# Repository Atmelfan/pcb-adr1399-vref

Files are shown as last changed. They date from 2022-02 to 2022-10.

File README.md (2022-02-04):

# pcb-adr1399-vref

**NOTICE** - The main branch is probably not production ready. Check out [Releases](https://github.com/Atmelfan/pcb-adr1399-vref/releases) for finished revisions.

A simple 10 V voltage reference based on [ADR1399](https://www.analog.com/en/products/adr1399.html) from Analog Devices.

# Schematic
Schematic
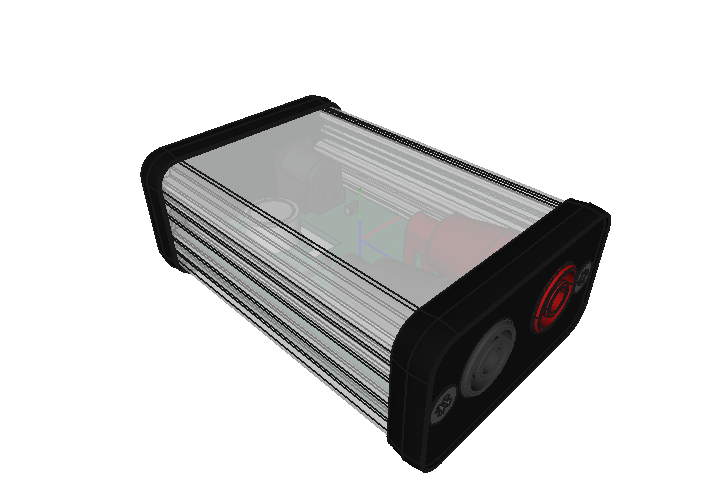
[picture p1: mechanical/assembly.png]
Assembly view


Check out [Releases](https://github.com/Atmelfan/pcb-adr1399-vref/releases) for revision schematics and materials.

# Tools used
* Schematic & Layout - [KiCad 6](https://www.kicad.org/)
* Assembly - [FreeCad 0.19](https://www.freecadweb.org/)

# License
This work is licensed under [CERN Open Hardware Licence Version 2 - Strongly Reciprocal](https://www.ohwr.org/project/cernohl/wikis/Documents/CERN-OHL-version-2).

See [LICENSE.txt](LICENSE.txt) for full text.

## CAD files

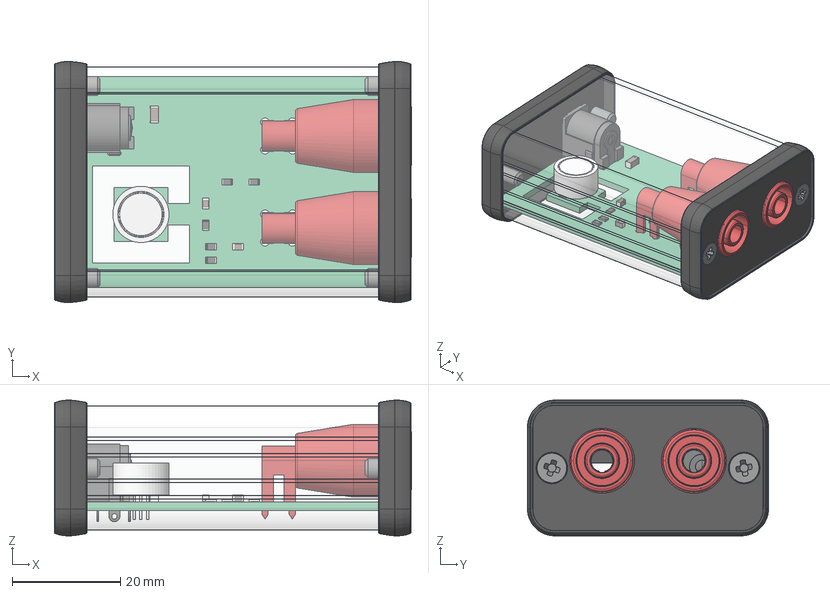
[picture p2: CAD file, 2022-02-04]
mechanical/assembly.step
66.1 x 44.6 x 25.1 mm
Extrusion Tube w. Inlay 60mm x 2
1455 Black screw x 2
1455 Black screw001 x 2
1455 Black screw002 x 2
1455 Black screw003 x 2
LCS x 2
Front Bezel x 2
Back Bezel x 2
Pcb_1364 x 2
J1_54-00130_0b9d4587839c x 2
R2_R_0805_2012Metric_4d09f17c0e32 x 10
C4_C_0805_2012Metric_924e94be286f x 6
J3_CT3151SP_0_b83ad89091ef x 4
U1_Analog_TO-46-4_ThermalShield_8fb0bece400e x 2
C1_C_1206_3216Metric_b3bb6e5f0510 x 2
LCS_Origin x 2

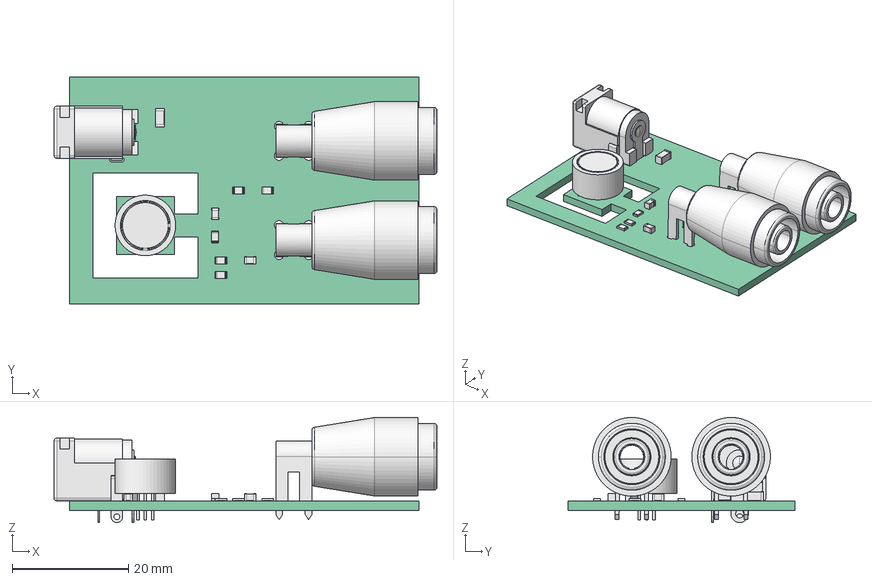
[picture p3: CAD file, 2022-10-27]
mechanical/board.FCStd
65.8 x 39.0 x 18.0 mm
Pcb_1364
J1_54-00130_0b9d4587839c
R2_R_0805_2012Metric_4d09f17c0e32 x 5
C4_C_0805_2012Metric_924e94be286f x 3
J3_CT3151SP_0_b83ad89091ef x 2
U1_Analog_TO-46-4_ThermalShield_8fb0bece400e
C1_C_1206_3216Metric_b3bb6e5f0510

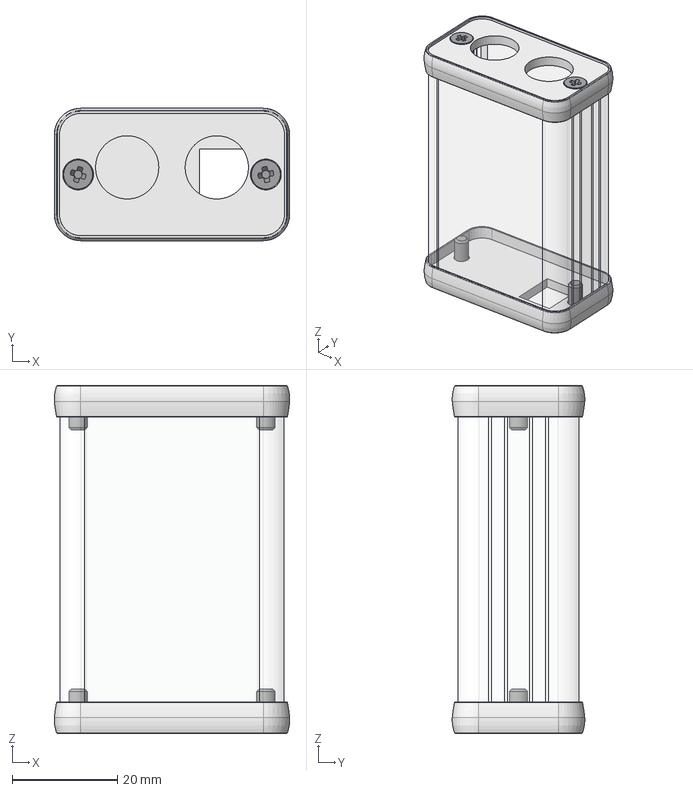
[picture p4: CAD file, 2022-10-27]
mechanical/box.FCStd
44.6 x 25.1 x 66.0 mm
Extrusion Tube w. Inlay 60mm
1455 Black screw
1455 Black screw001
1455 Black screw002
1455 Black screw003
Front Bezel
Back Bezel

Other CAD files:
mechanical/pcb.FCStd
mechanical/1455D602.stp
mechanical/assembly.FCStd
mechanical/assembly.stl

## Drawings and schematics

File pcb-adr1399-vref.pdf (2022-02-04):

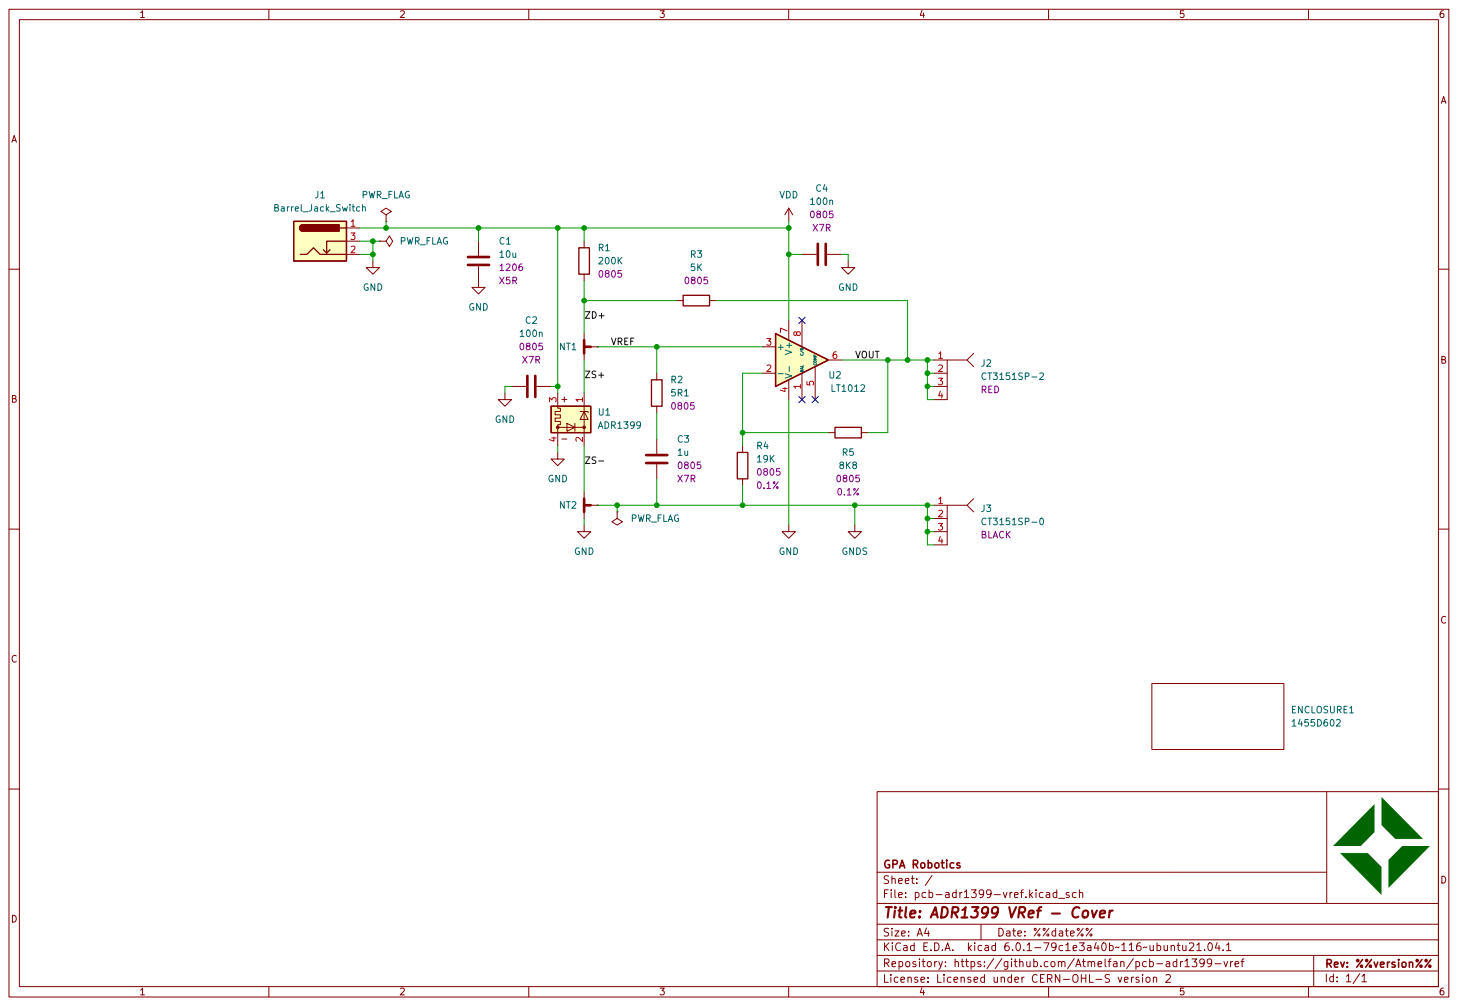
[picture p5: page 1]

File: pcb-adr1399-vref.kicad_sch Sheet: / GPA Robotics Repository: https://github.com/Atmelfan/pcb-adr1399-vref License: Licensed under CERN-OHL-S version 2 GND

D Date: %%date%%

Id: 1/1 Title: ADR1399 VRef - Cover

Size: A4

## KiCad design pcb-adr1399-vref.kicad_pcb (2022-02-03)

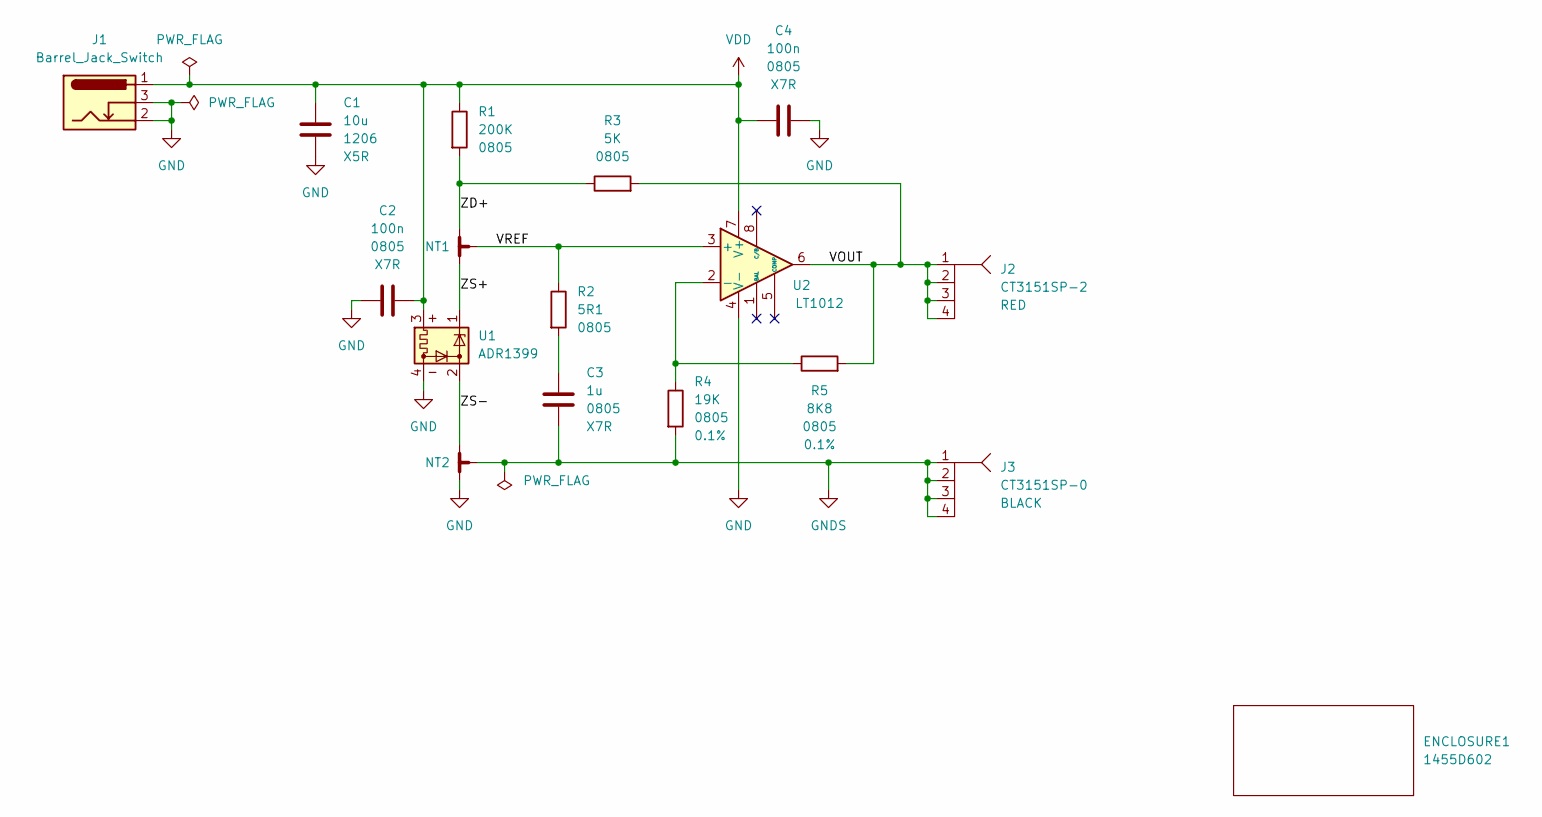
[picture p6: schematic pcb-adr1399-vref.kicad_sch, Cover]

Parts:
C1: 10u; C_1206_3216Metric_Pad1.33x1.80mm_HandSolder
C2, C4: 100n; C_0805_2012Metric_Pad1.18x1.45mm_HandSolder
C3: 1u; C_0805_2012Metric_Pad1.18x1.45mm_HandSolder
ENCLOSURE1: 1455D602; mpn 1455D602; digikey# HM1354-ND
J1: Barrel_Jack_Switch; 54-00130; mpn 54-00130; digikey# 839-1513-ND
J2: CT3151SP-2; CT3151SP; mpn CT3151SP-2; digikey# BKCT3151SP-2-ND
J3: CT3151SP-0; CT3151SP; mpn CT3151SP-0; digikey# BKCT3151SP-0-ND
NT1, NT2: NetTie_3_Tee; NetTie-3_SMD_Pad0.5mm
R1: 200K; R_0805_2012Metric_Pad1.20x1.40mm_HandSolder
R2: 5R1; R_0805_2012Metric_Pad1.20x1.40mm_HandSolder
R3: 5K; R_0805_2012Metric_Pad1.20x1.40mm_HandSolder
R4: 19K; R_0805_2012Metric_Pad1.20x1.40mm_HandSolder; Tolerance 0.1%
R5: 8K8; R_0805_2012Metric_Pad1.20x1.40mm_HandSolder; Tolerance 0.1%
U1: ADR1399; Analog_TO-46-4_ThermalShield
U2: LT1012; SO-8_3.9x4.9mm_P1.27mm; mpn LT1012ACS8#PBF; digikey# LT1012ACS8#PBF-ND

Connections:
/VOUT: J2.1, J2.2, J2.3, J2.4, R3.2, R5.2, U2.6
/VREF: NT1.3, R2.1, U2.3 (+)
/ZD+: NT1.2, R1.2, R3.1
/ZS+: NT1.1, U1.1
/ZS-: NT2.2, U1.2
GND: C1.2, C2.2, C4.2, J1.2, J1.3, NT2.1, U1.4, U2.4 (V-)
GNDS: C3.2, J3.1, J3.2, J3.3, J3.4, NT2.3, R4.2
unnamed: C3.1, R2.2
unnamed: R4.1, R5.1, U2.2 (-)
VDD: C1.1, C2.1, C4.1, J1.1, R1.1, U1.3, U2.7 (V+)

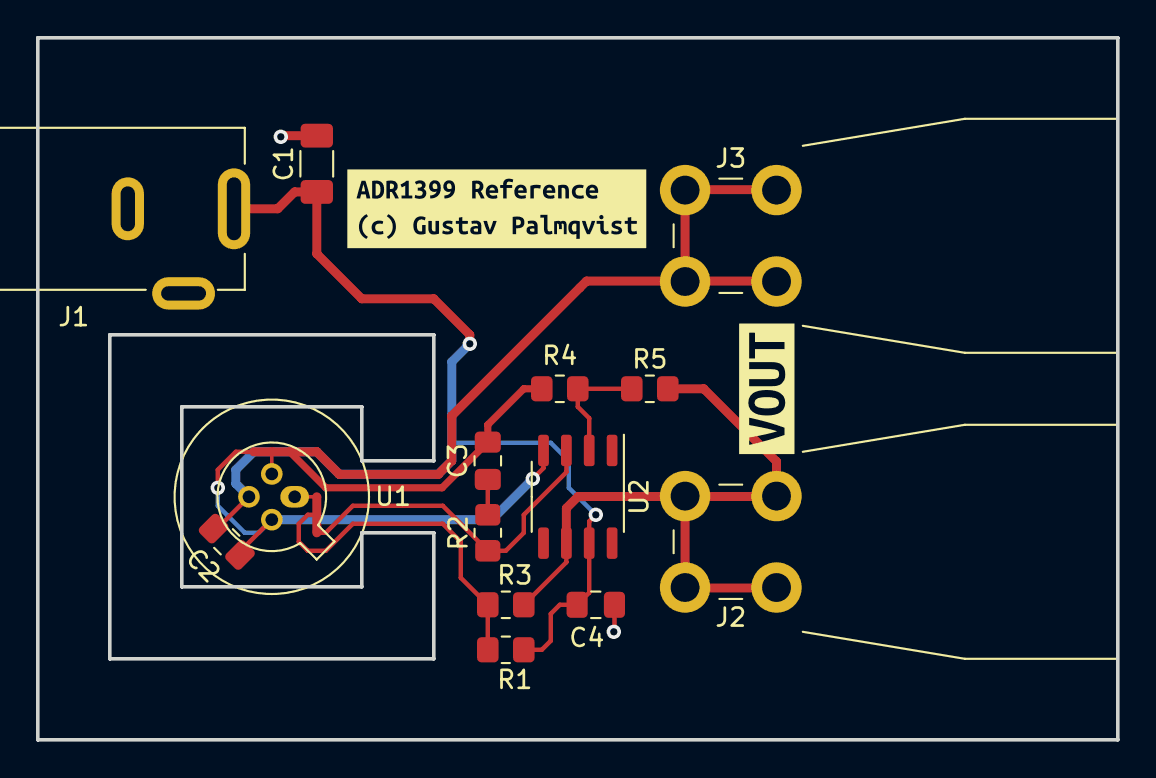
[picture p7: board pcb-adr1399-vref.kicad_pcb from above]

Board: 2 copper layers, 60.0 x 39.0 mm, 18 parts (0 on the bottom side), 10 nets.

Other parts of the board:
kibuzzard-61E8B62B: G***; kibuzzard-61E8B62B
kibuzzard-61FB27BC: G***; kibuzzard-61FB27BC

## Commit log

2022-01-21 First revision
    [pcb-adr1399-vref.kicad_pcb, pcb-adr1399-vref.kicad_sch]
2022-02-03 Ordered P1B
    [1455D602.stp, assembly.FCStd, board.FCStd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]
2022-02-03 Removed step file
    [pcb-adr1399-vref.step]
2022-02-03 Release schematics
